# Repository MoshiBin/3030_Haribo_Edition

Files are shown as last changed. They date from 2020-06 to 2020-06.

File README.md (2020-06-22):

# 3030 Haribo Edition



[teaser]: http://i.imgur.com/pz1YWP5.jpg "3030 Haribo Edition in Black"

credit: @arobe

## Unaffiliated Statement

We are **not** affiliated with Prusa Research and the work hereafter was done independently / derived from open source files

We are **not** affiliated with any Facebook group, any one claiming the haribo mod / haribo3030 / zaribo mod / etc is doing so on their own and it's not part of the effort

The **ONLY** official source is this github and the **ONLY** official channel to reach us is listed below (mattermost).  

## Contact us

Please join our [Mattermost](http://3dprinting.community) if you want to reach us.

There is a lot of different topics / channels on there, we welcome all with open arms.

## Disclaimer

**you do this modification at your own risk**

we are not responsible for any damages / injuries that might arise from the usage of all material, including but not limited to ideas, documentation, diagrams, that you get from this github.  All precautions and safety protection should be taken and only attempt it if you are experienced in this area.

## Introduction
Inspiration for the project came from [davtr](http://www.thingiverse.com/davtr/about) mk2 conversion [Prusa i3 MK2-X](http://www.thingiverse.com/thing:1692666)

The use of 3030 extrusion makes the frame very rigid and square.  It takes a lot of the guess work out of building the MK2

The name is from the candy that we get when we buy the MK2 kits.  Somebody jokingly said that's a good name and it sort of stuck.

We welcome any contribution to the project, just open a PR (pull request) and we will review and merge changes

## Haribo in the wild

S3D base settings

- 60mm/s 60% other speeds 30% first layer speed
- 80mm/s 50% other speeds 25% first layer speed
- 100mm/s 40% other speeds 20% first layer speed
- 120mm/s 30% other speeds 15% first layer speed

|\#|username|frame/color|Version|60mm/s|80mm/s|>100mm/s|
|-----|-----|-----|-----|-----|-----|-----|
|0|jtktam|Silver/Orange<br/>Silver/Red<br/>Black/Yellow||Yes|Yes|Yes|
|1|geoffreyc|Silver/Orange||Yes|Yes|Yes|
|2|[ar.o.be](http://imgur.com/a/lWbZ5)|Silver/Pineapple||Yes|Yes|Yes|
|3|[joostvwillegen](http://imgur.com/a/RYOfm)|Black/Metallic Gray<br/>Yellow/Carbon||Yes|Yes|Yes|
|4|chinooktx|Silver/Black||Yes|Yes|Yes|
|5|[skuiper](http://imgur.com/a/5j4W8)|Black/Purple+Green||Yes|Yes||
|6|JJ|Black/Violet|||||
|7|satmanager|Silver/Cherry Red||Yes|Yes||
|8|ryanneufeld|Black/Black|||||
|9|tricko|Black/Black+White||Yes|Yes|Yes|
|10|cube||||||
|11|[johnocfii](http://imgur.com/a/TPEzO)|Black/Jade||Yes|||
|12|[jasonh](http://imgur.com/a/vpMrx)|Silver/Transparent||Yes|Yes|Yes|
|13|jonasrh|Black/GITD green|||||
|14|[evad](http://imgur.com/a/PWNlf)|Silver/Silver||Yes|Yes|Yes|
|15|patrik||||||
|16|abjorshammar||||||
|17|stevendpclark||||||
|18|[arb](http://imgur.com/a/QF9FW)|Silver/Lime Green|||||
|19|[philsburry](http://imgur.com/a/lQyBh)|Silver/Translucent Blue|||||
|20|kaiserheld||||||
|21|tcolby|Silver/White|||||
|22|ollietwist|Silver/Orange|||||
|23|Jb3872|Black/Burgundy|||||
|24|unkle_rukus|Black/Neon Green||Yes|Yes|Yes|
|25|carre55|Black/Orange|||||
|26|dark-nico|Silver/Dark Green|||||
|27|olliet|Silver/Patchwork Colors|||||
|28|cova|Black/Translucent Blue|||||
|29|butthurt_beluga|Silver/Orange|||||
|30|jadam|Black/Black|||||
|31|bg|Silver/Patchwork Colors|||||
|32|curt.darius|Silver/Orange|||||
|33|evil4blue|Silver/Blue|||||
|34|nick|?|||||
|35|actibbs|Silver/Translucent Orange|||||
|36|Cappy175|Black/Lime Green|||||
|37|Grooperdude|Black/Dark Pruple|||||
|38|totalitarian||||||
|39|mloidl|Silver/Melon Yellow||Yes|Yes|Yes|
|40|IcicleTrepan|Black/Green|||||
|41|ballzyk0umpa|Black/Orange|||||
|42|[Dino](https://i.imgur.com/nfYLiFp.jpg)|Black/Pink|MK2.5|Yes|Yes|Yes|
|43|skydriver|Silver/Translucent Green||yes|yes|yes|
|44|kstiers|Black/Translucent Sapphire|||||
|45|christherock23|Black/SkyBlue||||
|46|RiskyBirdness|Silver/Red/Black||Yes|Yes|Yes|
|47|SkyDriver|Silver/Green Metallic||N/A|N/A|N/A| 
|48|cdunham1974|Silver/Translucent Magenta||N/A|N/A|N/A| 
|49|psynautic||||||
|50|[devsfan1830](https://imgur.com/gallery/Fj866qR)|Black/Orange|MK2.5||||
|51|[catrielmuller](https://imgur.com/gallery/VBMNfim)|Black/Black|MK2s MMU|Yes|Yes|Yes|

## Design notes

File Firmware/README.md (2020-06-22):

# Firmware

## Releases

Pre-compiled HEX releases can be found here: https://github.com/PrusaMK2Users/Prusa-Firmware/releases

## Introduction

The 3030 Haribo Edition frame has slightly more Z height than the stock Original Prusa i3 MK2. You will need to make some minor modifications to the firmware in order to accommodate for this.

## Warning

**Please Note:** Depending on the y carriage you use (stock or aftermarket), your mileage might vary.  Various y-carriages have different heights. I will note where you need to make the necessary changes and how to determine the values, but be ready to shut down the machine if it looks like it's going to crash the head into the bed!

## Configuration_prusa.h

Let's change the name of the printer:

```
// Printer name
#define CUSTOM_MENDEL_NAME "3030 Haribo Edition"
```

Let's set the correct Z_MAX_POS, the originial value is 210, and after a few test builds we determine 220 works on the MK2 and MK2s

so let's set it to 220:

```
#define Z_MAX_POS 220
```

If using the MK2.5 you'll need to change the Z_MAX_POS to 225mm due to the new MK52 bed

so let's set it to 225:

```
#define Z_MAX_POS 225
```

## Configuration.h

Since we are in here anyways, let's fix the encoder too:

```
#define ENCODER_PULSES_PER_STEP 2 // Increase if you have a high resolution encoder
#define ENCODER_STEPS_PER_MENU_ITEM 2 // Set according to ENCODER_PULSES_PER_STEP or your liking
```

to

```
#define ENCODER_PULSES_PER_STEP 4 // Increase if you have a high resolution encoder
#define ENCODER_STEPS_PER_MENU_ITEM 1 // Set according to ENCODER_PULSES_PER_STEP or your liking
```

## pins.h (optional)

Now depending which LCD board you have, you might find the rotary wheel direction is not intuitive (goes up when you expect down, down when up).  It's fairly easy to fix.  You need to invert 2 numbers in pins.h  

Find the first occurence of the following lines:
```
#define BTN_EN1 72
#define BTN_EN2 14
```

These are the atmega pin numbers assigned to the up and down motion of the menus.  To invert them, simply swap the numbers so the lines become:
```
#define BTN_EN1 14
#define BTN_EN2 72
```

## Final step

Now compile and upload the firmware.. redo your xyz calibration as normal

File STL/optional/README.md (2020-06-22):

# Optional STL

_These files are optional stuff to print for the Haribo Edition_

|Filename|Author|Description|
|-----|-----|-----|
|1x 67.75mm Jig.stl|jtktam|A jig to set the spacing of the left y rod holders to 67.75mm.  don't worry if it's not dead on, the idea is using this will ensure the front and back *LEFT* side y rod holders are the same distance from the left edge of the extrusion.  the holes are for M6 x 12 bolts and t-nuts, it's *suppose* to be loose so you can slide it in and out quickly.  Tested and it works to ensure the left side is good to go|
|1x_aftermarket_y_carriage_raiser.stl|jtktam (Joseph Tam)|three sc8uu block spacers and 1 belt holder spacer to raise the y carriage by 3.5mm to match the level of the stock y carriage|
|1x_fan-nozzle-haribo.scad<br/>1x_fan-nozzle-haribo.stl|jonasrh (Jonas Hansen)|a special version of the fan nozzle with "Haribo" on it|
|1x_lcd_cover.stl<br/>1x_lcd_cover.scad<br/>BPreplayBold.otf|Cova (Rob Baumstark)|Updated version of the LCD cover with '3030 Haribo Edition'. SCAD source included to generate custom LCD covers with your number in the corner and optionally updated text for dual-color.<br/>Included BPreplay font required to compile the SCAD source.|
|1x_lcd_cover_text.stl|Cova (Rob Baumstark)|STL of the text in the LCD cover for dual-color prints.|
|1x_lcd_mount_3030_clips.stl|nrepian|Modified LCD mount to use clips, rather than insert|
|1x_lcd_mount_3030_extra_contrast_clearance.stl|nrepian|3030 LCD clips with additional clearance for contrast pot|
|1x_lcd_mount_extra_contrast_clearance.stl|stevendpclark (Steven Clark)|A version of the LCD mounts that provide more clearance for the contrast pot for 3rd Party 2004 LCD Smart Controller Display boards.|
|1x_mk2x_y_belt_holder.stl|Mk2-x|demoted y belt holder|
|1x_mk2x_y_belt_holder_modded.stl|chinooktx (Pat Brochu)|modded y belt holder from mk2x (added 2mm)|
|1x_power_supply_box.stl<br/>1x_power_supply_mount.stl|jtktam (Joseph Tam)|Power supply mount and switch box for ebay PSU|
|1x_rambo_mount.stl|ryanneufeld (Ryan Neufeld)|Adapter plate to allow using the Prusa rambo enclosure.|
|1x_z_motor_mounts_three_screw.stl|dino (Garrett B)|Removed front inner screw holes to prevent collisions with pinda/fan nozzle|
|3x_double_y_bearing_housing.stl|Mk2-x|demoted y bearing holder|
|3x_SC8UU_LM8UU.stl|jtktam (Joseph Tam)|adapt lm8u to sc8uu block, use for aftermarket y carriage|
|3x_SC8UU_RZJM.stl|jtktam (Joseph Tam)|adapt igus rjzm to sc8uu block, use for aftermarket y carriage|
|3x_y_bearing_housing_lm8uu_short.stl|chinooktx (Pat Brochu)|adapt lm8uu to y belt bearing|
|3x_y_bearing_housing_rjzm_01_08.stl|chinooktx (Pat Brochu)|adapt igus rjzm to y belt bearing|
|7x_tsun_end_cap.stl|Cova (Rob Baumstark)|End caps designed to fit T-Sun 3030 extrusion|
|16mm Tnut Spacing|davvyk/dino (Garrett B)|Widened spacing between blocks to accomodate 15.8mm Tnuts|
|i3 Haribo Rambo Mount Thin.stl|ARBBB|Use for mounting standard rambo enclosure to the Haribo extrusions.|
|LED_Holder_Haribo_v3.stl | John O'Shaughnessy (johnocfii) and Patrik Rosén (patrik) | LED Strip/Bar Holders that attach to the back side of the Haribo frame.  Use this if you didn't use plastic L brackets on the top of the Z frame or if you did use plastic L brackets but only need a narrow area to hold your LEDs as the L brackets will prevent you from using the full back side of the extrusion.|
|LED_Holder_Haribo_v3_Bracket_Mount.stl | IcicleTrepan | Yet another alternate version of the excellent LED Strip/Bar Holder by John/Patrik.  This one can attach to the back side of the extrusion over top of the L brackets, giving you use of most of the back side of the Z frame's extrusion (still have to watch out for the hex screws).  NOTE:  It may be easier to install beside the bracket and then slide over the bracket than to install directly on the bracket.|
|LED_Holder_Haribo_v3_Reversed_Mount.stl | IcicleTrepan | Alternate version of the excellent LED Strip/Bar Holder by John/Patrik.  This one attaches to the front side of the Haribo frame.  Use this if you did use plastic L brackets on the Z frame and would like the holders spread out further.|
|LRS-350-12-bottom.stl|chinooktx (Pat Brochu)|Initial design for LRS-350-12 Meanwell Power Supply bottom cover|
|LRS-350-12-top.stl|chinooktx (Pat Brochu)|Initial design for LRS-350-12 Meanwell Power Supply top bracket|
|LRS-350-Neuf/LRS-350 Enclosure (lid and body) | Ryan Neufeld | Enclosure designed for IEC with integrated switch, and a removable lid for ease of access. Use M3x8mm fasteners w/ M3 nuts. Optionally you can use M3x10 or longer if you don't want to use nuts the hole beyond the nut is sized for direct threading of M3 fasteners.| 
|MK2S-modified-y-belt-holder.stl| Ryan Neufeld | A wider version of the stock mk2s belt holder, allows for re-positioning to better align with the PINDA when homing.|
|MK2S-modified-y-belt-holder-3mm-taller.stl| Ryan Neufeld | As above, only pushes the belt down 3mm, this is to be used in leiu of the belt holder spacer when using the half height bed frame.|
|Spool-holder-slide-top.stl|MoshiBin | A spool holder that sits on top of the frame, slides from the side of the top extrusion. Modeled to be similar to the "B4" MK3 spool mount.|

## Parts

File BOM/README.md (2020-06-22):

# I. Introduction
Below you will find the Bill of Materials for the **3030 Haribo Edition** build. This BOM will help you to either **upgrade** your **Original Prusa i3 MK2** or **scratch-build** a printer. Each section contains a subheading to indicate if it's required for an **upgrade** or just a **scratch-build**. If you have questions about this build, feel free to submit a Github issue and we will be glad to help you.

# II. Aluminum Frame Parts / Smooth Rods / Rubber Feet
#### Required For: **Upgrade** / **Scratch-Build**
This section contains the frame parts, smooth rods, t-slot nuts, and rubber feet that you will need.

If you live in the United States, the recommended seller of these parts is [Misumi US](https://us.misumi-ec.com/). To simplify the ordering process from Misumi, we have created a [Misumi CSV guide here](./MISUMI_CSV/README.md). You can simply download a pre-made data file and upload it to your cart to order all of the required parts.

If you would rather source the frame parts elsewhere, below is a list of all of the frame parts you will need.

#### Parts List

|Qty|Misumi Part #|Description|
|-----|-----|-----|
|3|HFS6-3030-354-Z8-XA12-XB342|Clear anodize 3030 Normal Rigidity Type extrusion 354mm 8mm counterbore hole @ 12mm and 342mm (x)|
|2|HFS6-3030-320-TPW-Z8-XA100|Clear anodize 3030 Normal Rigidity Type extrusion 320mm tap both ends 8mm counterbore hole @100mm (y)|
|2|HFS6-3030-330-TPW|Clear anodize 3030 Normal Rigidity Type 330mm tap both ends (z)|
|2|PSFG8-370|Hard Chrome Precision Linear Shaft - Straight 370mm (x)|
|2|PSFG8-360|Hard Chrome Precision Linear Shaft - Straight 360mm (y)|
|2|PSFG8-320|Hard Chrome Precision Linear Shaft - Straight 320mm (z)|
|1|PACK-HNTTSN6-6|Pre-Assembly Insertion Short Nuts -For HFS6 Series Aluminum Extrusions (100 per pack)|
|4|C-30-RK-3617|Rubber Feet|

#### Misc Misumi Parts (Scratch build only)

|Qty|Misumi Part #|Description|
|-----|-----|-----|
|2|WM5-15|Extruder Springs (5x15mm)|
|1|PSFR5-16|Extruder idler bearing rod(5x16mm)|

#### Spool Holder Parts List (OPTIONAL)
If you would like to build an integrated spool holder, there are a few other parts you will need.

|Qty|Misumi Part #|Description|
|-----|-----|-----|
|1|HFS6-3030-200-Z8-XA15|Clear anodize 3030 High Rigidity Type extrusion 200mm 8mm counterbore hole @ 15mm (spool holder vertical)|
|1|HFS6-3030-147-LTP|Clear anodize 3030 High Rigidity Type extrusion 147mm tap left end (spool holder horizontal)|
|1|SHBLBSL6|Brackets - 6 Series, Blind Brackets |

# III. Mounting Hardware
#### Required For: **Upgrade** / **Scratch-Build**

You will need some various nuts and bolts in order to assemble your **3030 Haribo Edition**. Below you will find a list of required hardware for both an upgrade build and a scratch printer build.

#### Recommended sources for this section (United States)
- [Bolt Depot](http://www.boltdepot.com/)
- [McMaster-Carr](https://www.mcmaster.com)
- [Fastenal](https://www.fastenal.com/)

#### Parts List
|Qty|Description|
|-----|-----|
|36|M6 washer|
|9|Socket Head Cap Screw M8 x 40mm|
|12|Socket Head Cap Screw M6 x 12mm|
|54|Socket Head Cap Screw M6 x 14mm|
|4|Socket Head Cap Screw M6 x 20mm|

# IV. Bushings
If you are upgrading from an Original Prusa i3 MK2, you may re-use the **LM8UU** bushings for X, Y and Z axes. However, you may consider swapping the X and Y axes with IGUS Drylin® Bushings. **Caution**: It is NOT recommended to use these bushings on the Z axis, as it is prone to binding on the **3030 Haribo Edition**.

#### Parts List
|Qty|Part #|Description|
|-----|-----|-----|
|6|RJ4JP-01-08|IGUS DRYLIN® Bushing|

#### Recommended sources for this section (United States)
- [Folger Technologies](https://goo.gl/oc9qrd)

# V. Scratch Build Parts
#### Required For: **Scratch-Build**
This section is only required for users who are building a **3030 Haribo Edition** from scratch.

#### Parts List

|Qty|Part #|Source|Description|
|-----|-----|-----|-----|
|1|PRI-UPG-MK2-ORG|[Prusa Research](https://goo.gl/39exUd)|Original Prusa i3 Plus to MK2 upgrade kit |
|1|-|[ultimachine](https://goo.gl/L4XLX0)|Rambo Mini v1.3 |
|1|LRS-350-12|[Arrow](https://goo.gl/zRQ6IZ) |Meanwell LRS-350-12 12V 29A 348W Power Supply |
|1|-|eBay / aliexpress|IEC power socket |
|1|-|eBay / aliexpress|Power switch |
|1|E-FAN-50-50-15|[e3D](https://goo.gl/qESKpZ)|50x50x15mm 12v DC Side Blow Fan |
|1|-|[RepRap Champion](https://goo.gl/xK2OkY) / eBay / aliexpress| Smart controller Reprap 2004 LCD |
|2|-|eBay / aliexpress|2x5 ribbon cable (>40cm) |
|-|-|Electronics Store|14awg power wire (black/red) |
|-|-|Electronics store|14awg ferrules |
|-|-|Electronics Store|Short zip ties (just get a bag full) |
|1|-|Electronics Store / Amazon | Wire loom (3/8" or 10mm) (For wire management)|
|1|-|[RepRap Champion](https://goo.gl/54I3IC) / eBay / aliexpress|Prusa i3 Universal Y Carriage Plate|
|2|-|[RepRap Champion](https://goo.gl/VUj4mo) / eBay / aliexpress|GT2 16T pulley|
|4|F623ZZ|eBay / aliexpress|F623ZZ 3x10x4mm flanged bearing. Put two of them together so the flange size faces out as belt idler. |
|1|104138|eBay / Hobby Store|HPI Blitz / Firestorm Titanium Idler Gear Shaft 5x16m #104138 (For extruder idler bearing rod)|
|4|-|[RepRap Champion](https://goo.gl/8F2Ub6) / eBay / aliexpress|LM8UU linear bearing (Bearings for the X Ends (Z Movement Direction) |
|8|-|McMaster / Fastenal / Bolt Depot | M3 fender washer |
|2|-|McMaster / Fastenal / Bolt Depot | M5 fender washer |
|4|-|McMaster / Fastenal / Bolt Depot | M2 washer |
|14|-|McMaster / Fastenal / Bolt Depot | M3 washer |
|6|-|McMaster / Fastenal / Bolt Depot | M3 square nut |
|2|-|McMaster / Fastenal / Bolt Depot | M3 lock nut|
|9|-|McMaster / Fastenal / Bolt Depot | M3 hex nut|
|4|-|McMaster / Fastenal / Bolt Depot | Socket Head Cap Screw M2 x 12mm|
|15|-|McMaster / Fastenal / Bolt Depot | Socket Head Cap Screw M3 x 10mm|
|6|-|McMaster / Fastenal / Bolt Depot | Socket Head Cap Screw M3 x 12mm|
|10|-|McMaster / Fastenal / Bolt Depot | Socket Head Cap Screw M3 x 18mm|
|3|-|McMaster / Fastenal / Bolt Depot |Socket Head Cap Screw M3 x 20mm|
|2|-|McMaster / Fastenal / Bolt Depot |Socket Head Cap Screw M3 x 25mm|
|3|-|McMaster / Fastenal / Bolt Depot |Socket Head Cap Screw M3 x 30mm|
|3|-|McMaster / Fastenal / Bolt Depot |Socket Head Cap Screw M3 x 40mm|
|5|-|McMaster / Fastenal / Bolt Depot |Button Head Cap Screw M3 x 8mm|
|4|-|McMaster / Fastenal / Bolt Depot |Button Head Cap Screw M3 x 10mm|
|2|-|McMaster / Fastenal / Bolt Depot |Button Head Cap Screw M3 x 12mm|
|4|-|McMaster / Fastenal / Bolt Depot |Button Head Cap Screw M4 x 6mm|
|9|-|McMaster / Fastenal / Bolt Depot |Socket Head Cap Screw M8 x 40mm|
|12|-|McMaster / Fastenal / Bolt Depot |Socket Head Cap Screw M6 x 12mm|
|54|-|McMaster / Fastenal / Bolt Depot |Socket Head Cap Screw M6 x 14mm|
|4|-|McMaster / Fastenal / Bolt Depot |Socket Head Cap Screw M6 x 20mm|

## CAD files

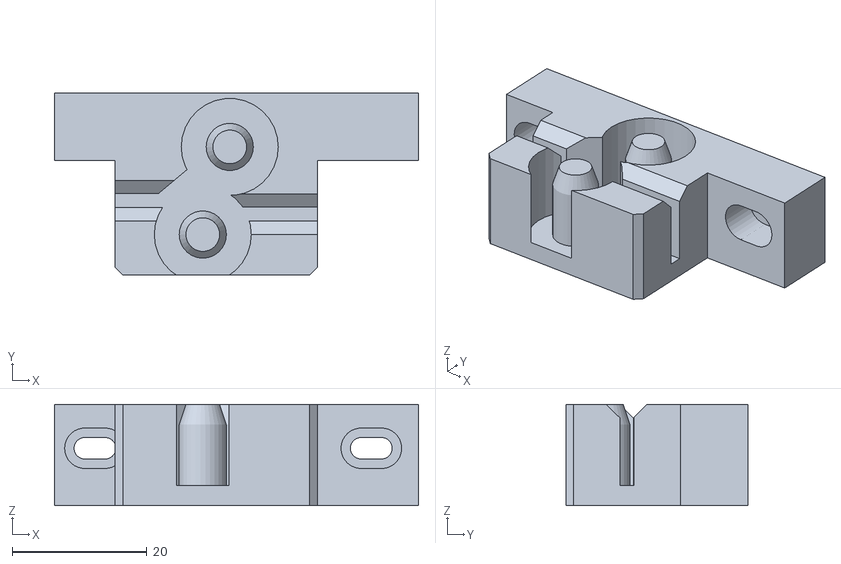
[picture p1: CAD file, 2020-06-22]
STL/1x_y_belt_holder.stl
54.0 x 27.0 x 15.0

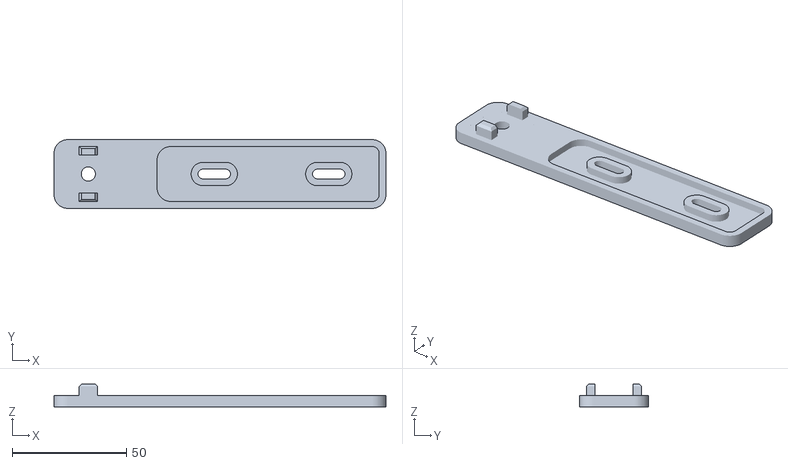
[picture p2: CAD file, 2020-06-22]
STL/optional/16mm Tnut Spacing/1x_LRS-350_psu_upper_strap_16mm.stl
145.0 x 30.0 x 10.0

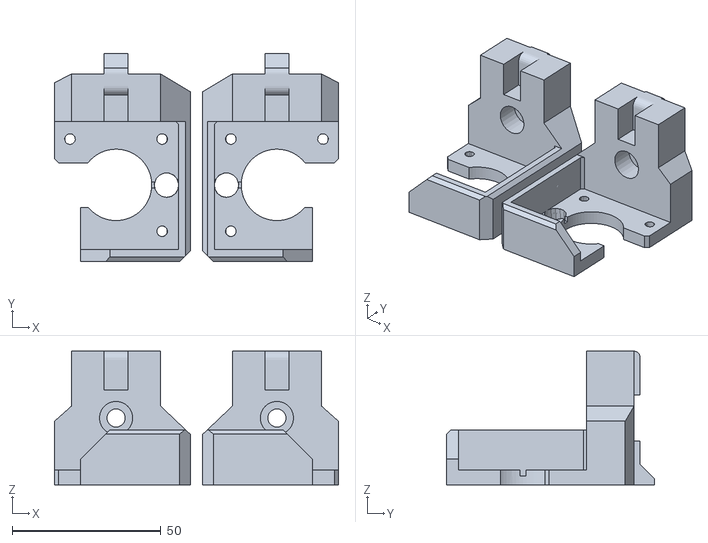
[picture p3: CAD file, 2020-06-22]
STL/optional/1x_z_motor_mounts_three_screw.stl
95.5 x 70.0 x 45.0

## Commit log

2020-06-22 Removed front inner screw holes to prevent collisions
    [1x_z_motor_mounts_three_screw.stl]
2020-06-22 Updating y-belt holder to be based on teh MK2S, extended by 2mm
    [1x_y_belt_holder.stl]
2020-06-22 Create mmu2 3030 frame brackets
2020-06-22 Add 16mm variation of LRS-350 upper strap
    [1x_LRS-350_psu_upper_strap_16mm.stl]
